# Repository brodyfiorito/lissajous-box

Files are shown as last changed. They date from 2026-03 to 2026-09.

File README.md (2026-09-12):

# Lissajous Figure Generator
A compact, standalone signal generator that produces phase- and frequency-controlled stereo sine waves for Lissajous figure visualization on an oscilloscope. Built around an ESP32-S3 and a PCM5102A stereo DAC, the device outputs two independent audio-frequency signals with real-time control over frequency ratio and phase offset via onboard potentiometers. It also functions as a USB-C audio speaker, with the ESP32-S3 acting as a USB audio device for music visualization on the oscilloscope.

## Overview
When two sine waves are fed into the X and Y inputs of an oscilloscope, the resulting trace is a Lissajous figure — a pattern whose shape is determined entirely by the frequency ratio and phase offset between the two signals. A 1:1 ratio at 90° produces a circle. A 2:1 ratio produces a figure eight. Higher integer ratios yield increasingly complex looping patterns.
Lissjous figure examples

It's a classic technique for visualizing the relationship between two signals, and the motivation behind this project. The device generates both signals digitally using an ESP32-S3 and outputs them through a PCM5102A stereo DAC, producing clean analog sine waves on two independent channels. Frequency ratio and phase offset are controlled via onboard potentiometers, making it a fully self-contained Lissajous generator.

### Key Features:
* Custom 2-layer PCB design in Altium Designer
* Dual-channel sine wave output via I²S audio DAC
* Real-time frequency ratio and phase offset control
* FreeRTOS-based firmware with state machine architecture
* USB-C audio input mode for music visualization.
* OLED display of frequency ratio and phase difference

## Hardware
### System Architecture
| Block | Component | Notes |
| --- | --- | --- |
| Microcontroller | ESP32-S3-WROOM-1-N4 |Dual-core, handles I²S output and control logic. Opens Bluetooth connectivity options |
| DAC | PCM5102A | 32-bit stereo audio DAC, I²S input |
| Power | TLV75733PDYDR | 1A LDO regulator; ESP32-S3 and PCM5102A draw well under 500mA combined |
| Input | 2x USB-C | One port used for programming the MCU, other used as a speaker |
| Output | 4x PCB Headers + JST male header | Left and right DAC output signals, plus two dedicated ground headers for oscilloscope probe referencing. OLED I²C port |

### Design Decisions

**LDO over buck converter:** The TLV75733PDYDR was chosen over a switching regulator specifically for noise performance. A buck converter operating at hundreds of kHz would inject switching noise onto the supply rail, which would appear directly on the PCM5102A analog output. An LDO produces a clean, low-noise 3.3V rail critical for signal integrity on an audio DAC.

**PCM5102A:** Selected for its stereo output and 32-bit resolution, providing more than enough dynamic range for clean sine wave generation. The internal charge pump also eliminates the need for an external negative supply rail, simplifying the power architecture.

**Output RC filter (1kΩ + 15nF):** The DAC output headers include a first-order low-pass filter with a cutoff frequency of ~10.6kHz. This was chosen to pass the full operating frequency range of 210–840Hz with minimal phase shift, while attenuating high-frequency noise and DAC imaging artifacts above the audio band. At 840Hz the phase shift introduced by this filter is under 5°, keeping both channels well-matched for accurate Lissajous figures.

**TVS diode on 5V input:** Protects the power rail from voltage transients on the USB input. USB ports can see inductive spikes during hot-plug events; the TVS clamps these before they reach the LDO or any downstream components.

**Color-coded test points:** Output headers use red (YRIGHT), white (XLEFT), and black (ground) test points to match standard oscilloscope probe color conventions, making it easy to connect the scope without referencing the schematic.

### Pin-Mapping
| Signal | GPIO | Notes |
| --- | --- | --- |
| OLED SDA | GPIO 1 | I²C data — OLED display |
| OLED SCL | GPIO 2 | I²C clock — OLED display |
| PHASE | GPIO 4 | Phase pot — ADC Channel 3 |
| FREQ | GPIO 5 | Frequency pot — ADC Channel 4 |
| MODE SWITCH | GPIO 6 | Mode selection switch |
| LRCK | GPIO 35 | I²S left/right clock |
| DOUT | GPIO 36 | I²S data out to DAC |
| BCK | GPIO 37 | I²S bit clock |
| SCK | GPIO 38 | I²S system clock (MCLK) |

### Schematics
All schematics were captured in Altium Designer.

Sheet 1

_Sheet 1 — Input/Output: Dual USB-C connectors (speaker and programming), CP2102-GMR USB-to-UART bridge for MCU programming, phase difference and frequency potentiometer inputs with R-C filtering, left and right DAC output headers with 1k series resistors and 15nF shunt capacitors, and USB D+/D− data lines with 22Ω series resistors._

Sheet 2

_Sheet 2 — Power: 5V to 3.3V regulation via TLV75733PDYDR LDO. Input is protected by a TVS diode with 1µF and 0.1µF decoupling capacitors. The EN pin is controlled by a 2.2kΩ/5kΩ resistor divider tied to the XSMT soft-mute signal. Output is decoupled with a 10µF capacitor, and a power indicator LED is driven through a 680Ω current-limiting resistor._

Sheet 3

_Sheet 3 — Audio: PCM5102A stereo DAC receiving I²S signals (SCK, BCK, DOUT, LRCK) from the ESP32-S3. AVDD, CPVDD, and DVDD are all supplied from 3.3V with 10µF and 0.1µF decoupling. Internal charge pump is supported by 2.2µF capacitors on CAPP and CAPM. Left (OUTL) and right (OUTR) analog outputs are routed to the output header section. XSMT soft-mute is tied to the power section EN divider._

Sheet 4

_Sheet 4 — MCU: ESP32-S3-WROOM-1-N4 with 10µF and 0.1µF decoupling on the 3.3V rail. I²S signals (LRCK, DOUT, BCK, SCK) are routed to the PCM5102A. UART RX/TX connect to the CP2102-GMR programming bridge via RTS/DTR auto-reset circuit — RTS and DTR signals drive NPN transistors through base resistors to control the EN and IO0 pins for automatic bootloader entry. USB D+/D− are broken out for USB audio (speaker) mode. Analog inputs receive the phase difference and frequency potentiometer signals. A mode selection switch with pull-down resistor and debounce capacitor is included. I²C lines (SCL, SDA) are broken out for the optional OLED display with decoupling on the supply line._

### Bill of Materials
| Ref | Description | Value / Part | Package | Qty |
|-----|---|---|---|-----|
| MCU | WiFi/BT Module | ESP32-S3-WROOM-1-N4 | SMD Module | 1 |
| DAC | Stereo DAC | PCM5102APWR | 20-TSSOP | 1 |
| PROG | USB-to-UART Bridge | CP2102-GMR | 28-QFN | 1 |
| U1 | LDO Regulator | TLV75733PDYDR | SOT-23-5 | 1 |
| J1, J2 | USB-C Connector | 2012670005 | SMD RA | 2 |
| P1 | OLED Header | Male Header 2mm 1×4 | 4-Pin THD | 1 |
| Q1, Q2 | NPN Transistor | SOT-1123 | SOT-1123 | 2 |
| R11 | Phase Potentiometer | ALPS RK11K1140A3L | 4-Pin THD | 1 |
| R12 | Frequency Potentiometer | ALPS RK11K1140A3L | 4-Pin THD | 1 |
| SW1 | Slide Switch | SPST 4A 125V | THD | 1 |
| R1–R4, R14 | Resistor | 5kΩ | 0603 | 5 |
| R5, R6, R9, R10 | Resistor | 1kΩ 1% 0.1W | 0603 | 4 |
| R7, R8 | Resistor | 22Ω 5% 0.1W | 0603 | 2 |
| R13 | Resistor | 2.2kΩ 1% 0.1W | 0603 | 1 |
| R15 | Resistor | 680Ω 5% | 0603 | 1 |
| R16, R17, R18 | Resistor | 10kΩ 0.1% | 0603 | 3 |
| C1, C7, C18 | Capacitor | 1µF | 0603 | 3 |
| C2, C3, C4, C9, C10, C11, C14, C16 | Capacitor | 0.1µF X7R | 0603 | 8 |
| C5, C6 | Capacitor | 15nF X7R | 0603 | 2 |
| C8, C15, C17 | Capacitor | 10µF X5R | 0603 | 3 |
| C12, C13 | Capacitor | 2.2µF X7S | 0603 | 2 |
| D1 | TVS Diode | 5V / 14V | 2×2 SON | 1 |
| D2 | LED | Red Clear | 2-SMD | 1 |
| SGND1, SGND2 | Test Point | Black Miniature | — | 2 |
| XLEFT | Test Point | White Miniature | — | 1 |
| YRIGHT | Test Point | Red Miniature | — | 1 |

### PCB Layout

PCB Top Layer

_Top copper layer showing primary signal and power routing. Stitching vias connect the top and bottom ground pours at regular intervals to minimize ground impedance and keep return current loops short._

PCB Bottom Layer

_Bottom copper layer. The continuous ground pour provides a low-impedance return path and acts as an electric field shield across the full board area._

PCB 3D View

_3D render of the assembled board. Controls (phase, frequency, mode) are grouped on the left edge; the DAC and analog outputs are isolated to the right edge away from the MCU and power circuitry._

#### Board Specifications
| Property | Value |
|---|---|
| Dimensions | 84 mm × 58 mm |
| Thickness | 1.6 mm |
| Finish | HASL |
| Layers | 2 |
| Top Layer | Primary signal and power routing |
| Bottom Layer | Ground plane |

#### Layer Stackup
Both layers carry continuous ground pours. The bottom ground plane serves as a low-impedance return path and voltage reference for analog signals, while the surrounding copper on both layers reduces capacitive coupling of external noise onto sensitive traces.

#### Placement
The CP2102 USB-UART bridge sits adjacent to the programming USB-C connector to keep the USB differential pair short. Decoupling capacitors are placed as close as possible to each IC's power pins to minimize supply rail loop inductance. The stereo DAC and analog output network are isolated to one edge of the board, maximizing separation from the ESP32 and power circuitry. The ESP32-S3 module antenna keepout area is free of copper pours and routing on all layers.

#### Routing
Ground vias are distributed across the board to connect the top and bottom ground pours, reducing ground impedance and keeping return current loops short.
Signal traces crossing power traces do so at 90° to minimize inter-layer capacitive coupling.
Analog output traces are routed away from digital and power traces for the full length of the board.

## Controls

The device has three physical controls: two potentiometers and a mode slide switch.

| Control | Function |
|---|---|
| Frequency pot | Selects frequency ratio between channels |
| Phase pot | Selects phase offset between channels |
| Mode switch | Toggles between Lissajous generator and USB audio input modes |

### Frequency Ratios
| Pot Position | Ratio | Pattern |
|---|---|---|
| 1 | 1:1 | Ellipse / circle |
| 2 | 2:1 | Figure eight |
| 3 | 3:1 | Three-lobed curve |
| 4 | 4:1 | Four-lobed curve |
| 5 | 1:2 | Horizontal figure eight |
| 6 | 3:2 | Three/two curve |
| 7 | 4:3 | Four/three curve |
| 8 | 6:5 | Six/five curve |

### Phase Steps
| Pot Position | Phase Offset |
|---|---|
| 1 | 0 |
| 2 | π/8 |
| 3 | π/4 |
| 4 | 3π/8 |
| 5 | π/2 |
| 6 | 5π/8 |
| 7 | 3π/4 |
| 8 | 7π/8 |

### Modes
**Lissajous Mode** — The ESP32-S3 generates both sine wave channels internally. Frequency ratio and phase offset are controlled via the onboard potentiometers. Connect XLEFT and YRIGHT outputs to the X and Y inputs of an oscilloscope in XY mode.

**Audio Input Mode** — The ESP32-S3 enumerates as a USB audio device. Audio played from a connected computer is passed through to the DAC outputs, allowing music to be visualized on the oscilloscope in XY mode.

## Firmware

The firmware is written in Embedded C using the ESP-IDF framework with FreeRTOS. Sine wave generation uses a phase accumulator, rather than computing sine values from absolute time, each sample increments a floating-point phase register by a step size proportional to the desired frequency, which avoids unbounded growth of the time variable. I²S is used to communicate with the DAC and I²C is used to communicate with the OLED controller.

### Architecture Highlights:
* FreeRTOS task handles I²S DMA buffer filling at audio sample rate
* State machine manages mode switching
* Phase accumulator for drift-free, long-term stability
* Exponential moving average + hysteresis on ADC pot readings to prevent jitter and snap between ratio/phase steps cleanly
* OLED display continuously updated via I²C with current frequency ratio and phase offset

Built with ESP-IDF v5.5.2

### Base Frequency Selection
The base frequency is 210Hz against a 44.1kHz sample rate, which is exactly 210 samples per cycle. Choosing a base frequency that divides evenly into the sample rate matters more than the specific value: any fractional remainder leaves a sub-sample timing error that accumulates cycle over cycle, and because the Lissajous figure is a picture of the phase relationship between the two channels, that error shows up directly as a figure that slowly precesses instead of standing still. See [Troubleshooting](#firmware-bring-up-and-troubleshooting) below.

## Development
### Devkit Prototype
Initial development and firmware validation were done on an ESP32-S3 devkit connected to a PCM5102A breakout board. During testing, the left channel output of the PCM5102A breakout was found to be non-functional. The right channel operated correctly. To rule out a firmware bug, the left and right channels were swapped in software, confirming the issue was a hardware fault on the breakout module rather than anything in the code. A bench signal generator was substituted as the left channel input to the oscilloscope, allowing firmware validation and Lissajous figure generation to continue. Outside of the broken channel, the devkit setup was used to fully validate the signal generation algorithm, I²S configuration, and oscilloscope output before committing to PCB layout.

ESP32 on a breadboard
_Breadboard prototype — ESP32-S3 devkit connected to PCM5102A breakout via jumper wires. Oscilloscope probe attached to OUTR and ground. Phase and frequency potentiometers wired in via jumper wires._

Two sine waves
_Rigol DS1102E oscilloscope showing early firmware output. CH1 (yellow) is the signal generator left channel reference, CH2 (blue) is OUTR from the PCM5102A; both set to 210Hz. The frequency readout is being thrown off by noise on the signals._

<video src="https://github.com/user-attachments/assets/7f4eb666-647e-48f4-968a-9c4041df8248" controls width="600"></video>
_Rigol DS1102E in XY mode. 210Hz on both channels with a phase offset producing a rotating ellipse pattern. CH1 (signal generator) on the X axis, CH2 (PCM5102A OUTR) on the Y axis._

### Firmware Bring-Up and Troubleshooting

Bring-up was done in order — supply rails, then I²S clocking, then the output waveforms — rather than by probing around. The Lissajous figure itself is a useful test signal: a 1:1 ratio at 90° should be a stationary circle, so anything wrong with channel amplitude matching, phase, or timing distorts the figure in a characteristic way. Every fault below was found on the devkit before the PCB was laid out.

#### No output — I²S clock configuration
The DAC produced nothing on either channel initially. The PCM5102A breakout ties SCK to ground internally, which puts the part in its internal-PLL mode and means it must not be fed an external master clock. Driving MCLK from the ESP32 anyway prevented the PLL from locking. The fix was to set MCLK to `I2S_GPIO_UNUSED` in the channel config, remove the manual `gpio_config()` calls that were being applied to the I²S pins (the I²S driver configures them itself), and bond the devkit and breakout grounds together rather than relying on separate supply returns.

#### Watchdog resets
Two separate causes. First, the `PI` constant was defined without an `f` suffix, which promoted the entire per-sample sine computation to double precision — the ESP32-S3 has no double-precision FPU, so the buffer fill loop no longer finished within its budget. Second, `ESP_LOGI` calls left inside the per-sample loop were writing to UART thousands of times per buffer. Adding the `f` suffix and pulling logging out of the inner loop resolved both.

#### Silent output before the first ADC read
`freqRatio` and `phaseDiff` were declared as `volatile float` globals with no initializer, so they were zero until `adc_task` completed its first read. With `freqRatio` at zero, the right channel step size was zero and its accumulator never advanced, producing a DC level instead of a sine. Initializing them to `1.0f` and `PI / 2.0f` means the I²S task generates a valid signal from the first buffer.

#### Precessing figure
With both channels at the same frequency and a fixed phase offset, the figure should be completely stationary. Instead it smeared into a blob. The base frequency at the time was 200Hz, which is 220.5 samples per cycle at 44.1kHz — the half-sample remainder accumulated as a slowly growing phase error between the channels, rotating the ellipse continuously. Moving the base frequency to 210Hz (exactly 210 samples per cycle) locked the figure in place.

#### Discontinuities at buffer boundaries
`freqRatio` and `phaseDiff` were being read inside the per-sample loop, so `adc_task` could change them partway through a buffer fill and split one buffer across two different parameter sets. Both are now snapshotted once at the top of each buffer fill and not re-read until the next one. Separately, the two accumulators were advancing independently, which allowed them to drift apart over long runtimes; the right channel phase is now derived from the left rather than accumulated on its own.

#### Periodic spikes on the sine output — phase accumulator
The most instructive fault. The output carried sharp spikes riding on an otherwise clean sine, frequent enough to destabilize the scope's frequency readout. Mains coupling was the obvious suspect: this was a breadboard with long jumper leads, and real 60Hz pickup had already turned up earlier in the project on a floating output.

The spectrum settled it. Coupled mains is an independent signal, so its energy lands at 60Hz and multiples of 60Hz, which are incommensurate with a 210Hz fundamental. The FFT instead showed a dip at 60Hz and energy at exact multiples of 210Hz. Harmonically related energy means the waveform's own shape is wrong — distortion generated inside the signal chain, periodic at the signal rate — rather than something unrelated being added to it from outside. A sharp, narrow glitch occurring once per output cycle spreads energy broadly across the harmonic series, which is exactly the signature observed.

That narrowed it to the generation path, and the time-domain trace confirmed it: the waveform was snapping back to θ = 0 rather than wrapping smoothly. The accumulator was being reset instead of reduced modulo 2π, so every wrap threw away the fractional phase advance and inserted a discontinuity. Wrapping by subtracting 2π when the accumulator passes it, and snapshotting parameters per buffer as described above, removed the spikes.

The general form is worth keeping on the bench: **harmonically related energy points at your own signal chain; unrelated frequencies point at the outside world.**

accumulator-error

_Phase accumulator resetting instead of wrapping. CH2 (blue) is OUTR from the PCM5102A — the trace climbs and then snaps back discontinuously once per cycle instead of turning over smoothly. CH1 (yellow) is the bench signal generator reference at 209.994Hz. Note that the FFT shown in the lower pane is sourced from CH1, not CH2 — this capture documents the time-domain reset, not the harmonic spectrum that ruled out mains coupling._

#### ADC filtering
The exponential moving average on the pot readings had its coefficients inverted — 5% previous value, 95% new sample — which is effectively no filtering, and the displayed ratio and phase jittered constantly. Corrected to 95% previous, 5% new, with a hysteresis window on top so the output only snaps to a new ratio or phase step once the pot has clearly moved into it.

#### Dead code
A zero-crossing block that reassigned `fL = base_freq` inside the buffer fill loop was removed. It was a leftover from an earlier attempt at dynamic frequency updates and did nothing, since `fL` never changes; the phase accumulator needs no zero-crossing alignment to stay stable.

### Validated Output

Captures taken after the firmware fixes above, on the Rigol DS1102E in XY mode. CH1 on the X axis at 950mV/div, CH2 on the Y axis at 100mV/div, 100.0kSa. Each figure is stationary rather than drifting, which is the real result — a stable figure means both channels agree on frequency and hold a constant phase relationship indefinitely.

1:1 ratio, 45 degree phase offset

_1:1 ratio at 45° phase offset — a tilted ellipse. At 0° this collapses to a diagonal line and at 90° it opens into a circle, so the tilt and openness of the ellipse read directly as the phase offset between channels._

1:2 ratio, 0 degree phase offset

_1:2 ratio at 0° phase offset — horizontal figure eight. The two lobes are symmetric and the crossing point sits centered, indicating matched amplitude between channels._

1:3 ratio, 0 degree phase offset

_1:3 ratio at 0° phase offset. At zero phase the figure is degenerate: the curve doubles back on itself and is retraced in both directions rather than enclosing separate lobes, so the trace appears as a single open path._

1:3 ratio, 15 degree phase offset

_1:3 ratio at 15°. Introducing phase separates the outbound and return paths, and the degenerate curve begins to open into distinct loops._

1:3 ratio, 30 degree phase offset

_1:3 ratio at 30°. The loops are fully separated. Sweeping phase at a fixed ratio walks the figure continuously between the degenerate and fully open forms._

### PCB Assembly

PCBs were fabricated by JLCPCB (2-layer, HASL, 1.6mm). Solder paste was applied manually using a stencil, SMD components were placed by hand and reflowed. Through-hole components (potentiometers, slide switch, OLED header, output headers) were hand soldered after reflow.

taped

_Solder paste applied prior to reflow. Board taped down to prevent shifting._

reflow

_Post-reflow. Through-hole components not yet installed._

firstrev

_Fully assembled and powered up. Power LED on, wires soldered to ESP32 for manual bootloader entry while programming, wires replaced with jumpers after firmware was validated._

The SOT-1123 NPN transistors used for the CP2102 auto-reset circuit were lost during reflow and could not be recovered. The package is too small to place reliably by hand. Manual bootloader entry (hold BOOT, cycle reset) is required for programming.

## Enclosure
The enclosure was designed in Fusion 360 to fit the PCB. It features cutouts for the two potentiometers, the mode slide switch, and the SSD1306 OLED display, as well as openings for the speaker output jack, USB-C port, and the dual oscilloscope output connectors. Intended for FDM printing in PLA.

STL and STEP files for the box and face plate are available in the `/enclosure` directory.

lissajous-box-view2
_Fusion 360 render of the enclosure._

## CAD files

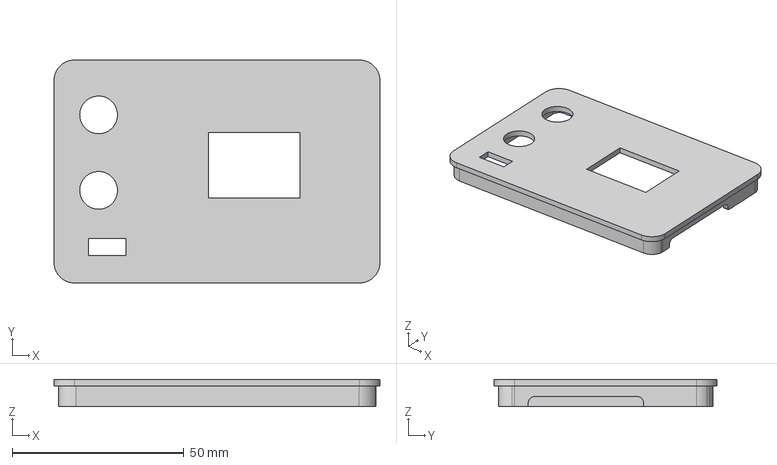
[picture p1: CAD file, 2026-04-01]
enclosure/Face Plate.step
95.0 x 65.0 x 8.00 mm

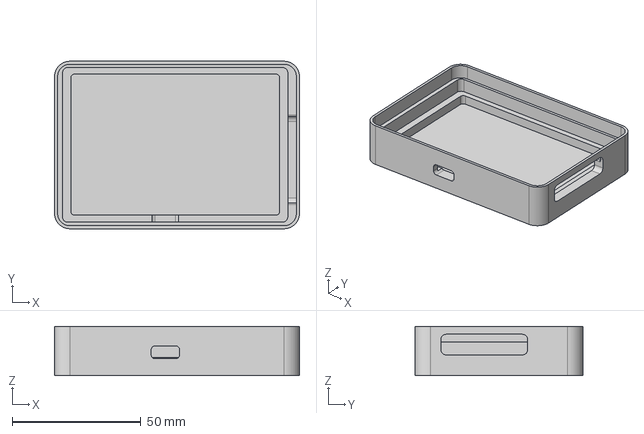
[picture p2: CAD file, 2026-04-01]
enclosure/Box.step
95.0 x 65.0 x 19.0 mm

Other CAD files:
enclosure/Box.stl
enclosure/Face Plate.stl

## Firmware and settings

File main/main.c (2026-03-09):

// Brody Fiorito 2026
// Lissajous Box - main.c
// Generates stereo sine waves with adjustable frequency ratio and phase offset
// for Lissajous figure display. 
// Also supports USB audio passthrough mode for music visualization.

#include <stdio.h>
#include <driver/uart.h>
#include <string.h>
#include <driver/gpio.h>
#include <driver/i2s_std.h>
#include <freertos/FreeRTOS.h>
#include <freertos/task.h>
#include <esp_adc/adc_cali.h>
#include <esp_adc/adc_cali_scheme.h>
#include <esp_adc/adc_oneshot.h>
#include <math.h>
#include <usb_device_uac.h>
#include <freertos/ringbuf.h>
#include "esp_log.h"

// Hardware Pins
#define LRCK_PIN GPIO_NUM_35
#define DOUT_PIN GPIO_NUM_36
#define BCK_PIN GPIO_NUM_37
#define SCK_PIN GPIO_NUM_38

#define PHASE_PIN GPIO_NUM_4
#define FREQ_PIN GPIO_NUM_5
#define PHASE_ADC_CHANNEL ADC_CHANNEL_3
#define FREQ_ADC_CHANNEL ADC_CHANNEL_4
#define MODE_SWITCH_PIN GPIO_NUM_9

// Constants
#define PI 3.14159265358979f
#define UAC_RX_BUFSIZE 4096
#define ADC_MV_MAX 3200.0f

// Global State
static RingbufHandle_t audio_ringbuf = NULL;

static i2s_chan_handle_t tx_chan;

volatile float freq_ratio = 1.0f;       // Shared between i2s_task and adc_task. Volatile prevents the compiler
volatile float phase_diff = PI / 2.0f;  // from optimizing reads into a register, ensuring the latest value is always used.

typedef struct {
    int last_raw;
    float smooth;
} adc_ctrl_t;

adc_ctrl_t freq_ctrl = { .last_raw = 0, .smooth = 0 };
adc_ctrl_t phase_ctrl = { .last_raw = 0, .smooth = 0 };

typedef enum {
    MODE_LISSAJOUS = 0,
    MODE_AUDIO_INPUT = 1
} system_state_t;

TaskHandle_t adc_sampling_handle = NULL;
TaskHandle_t audio_input_handle = NULL;
TaskHandle_t i2s_handle = NULL;

static system_state_t current_mode = MODE_LISSAJOUS;
static system_state_t requested_mode = MODE_LISSAJOUS;

// Function prototypes
void adc_task(void *arg);
void i2s_task(void *arg);
void audio_input_task(void *arg);
int adc_hysteresis(adc_ctrl_t *c, int);
float adc_smooth(adc_ctrl_t *c, int);
float get_ratio(float);
float get_phase_diff(float);
static esp_err_t uac_output_callback(uint8_t *buf, size_t len, void *cb_ctx);
void enter_mode(system_state_t);
static system_state_t read_mode_switch(void);

void i2s_task (void *arg) {

    // I2S Configuration
    i2s_chan_config_t chan_config = I2S_CHANNEL_DEFAULT_CONFIG(
        I2S_NUM_0,
        I2S_ROLE_MASTER
    );

    i2s_std_config_t i2s_config = {
        .clk_cfg = I2S_STD_CLK_DEFAULT_CONFIG(44100),

        .slot_cfg = I2S_STD_PHILIPS_SLOT_DEFAULT_CONFIG(
            I2S_DATA_BIT_WIDTH_16BIT,
            I2S_SLOT_MODE_STEREO
        ),

        .gpio_cfg = {
            .mclk = I2S_GPIO_UNUSED,
            .bclk = BCK_PIN,
            .ws = LRCK_PIN,
            .dout = DOUT_PIN,
            .din = I2S_GPIO_UNUSED,
            .invert_flags = {
                .mclk_inv = false,
                .bclk_inv = false,
                .ws_inv = false,
            },
        },
    };

    i2s_new_channel(&chan_config, &tx_chan, NULL);
    i2s_channel_init_std_mode(tx_chan, &i2s_config);
    i2s_channel_enable(tx_chan);

    const float base_freq = 210.0f;
    float phaseL = 0.0f;
    const float sample_rate = 44100.0f;
    const int BUFFER_SIZE = 256;
    int16_t buffer[BUFFER_SIZE * 2];

    while (1) {

        if (current_mode == MODE_LISSAJOUS) {

            float fL = base_freq;

            for (int i = 0; i < BUFFER_SIZE; i++) {
                float sampleL = sinf(phaseL);
                float sampleR = sinf(phaseL * freq_ratio + phase_diff);

                buffer[i*2 + 0] = (int16_t)(sampleL * 0x7FFF);
                buffer[i*2 + 1] = (int16_t)(sampleR * 0x7FFF);

                phaseL += 2.0f * PI * fL / sample_rate;

                if (phaseL >= 2.0f * PI) phaseL -= 2.0f * PI;
            }

            size_t bytes_written;
            i2s_channel_write(tx_chan, buffer, sizeof(buffer), &bytes_written, portMAX_DELAY);

        } else if (current_mode == MODE_AUDIO_INPUT) {

            if (audio_ringbuf == NULL) {
                vTaskDelay(pdMS_TO_TICKS(10));
                continue;
            }

            size_t bytes_available;
            uint8_t *data = (uint8_t *)xRingbufferReceiveUpTo(
                audio_ringbuf,
                &bytes_available,
                pdMS_TO_TICKS(20),  // Block up to 20ms waiting for data; sizeof(buffer) caps the read to our
                sizeof(buffer)      // output buffer size. If no data arrives we loop and retry rather than stall.
            );

            if (data && bytes_available > 0) {
                size_t bytes_written;
                i2s_channel_write(tx_chan, data, bytes_available, &bytes_written, portMAX_DELAY);
                vRingbufferReturnItem(audio_ringbuf, data);
            }

        } else {
            // Should never reach here - unknown mode, yield to prevent CPU starvation
            vTaskDelay(1);
        }
    }
}

void adc_task(void *arg) {

    // Initialize ADC1 in oneshot mode for reading frequency and phase control potentiometers.
    // Oneshot mode is used instead of continuous mode since we only need periodic readings
    // at 10ms intervals, not a high-speed stream.
    adc_oneshot_unit_handle_t adc_handle;

    adc_oneshot_unit_init_cfg_t init_config = {
        .unit_id = ADC_UNIT_1
    };

    adc_oneshot_new_unit(&init_config, &adc_handle);

    adc_oneshot_chan_cfg_t chan_cfg = {
        .atten = ADC_ATTEN_DB_12,
        .bitwidth = ADC_BITWIDTH_12,
    };

    adc_oneshot_config_channel(adc_handle, FREQ_ADC_CHANNEL, &chan_cfg);

    adc_oneshot_config_channel(adc_handle, PHASE_ADC_CHANNEL, &chan_cfg);

    adc_cali_handle_t cali_handle;

    adc_cali_curve_fitting_config_t cali_cfg = {
        .unit_id = ADC_UNIT_1,
        .atten = ADC_ATTEN_DB_12,
        .bitwidth = ADC_BITWIDTH_12,
    };

    adc_cali_create_scheme_curve_fitting(&cali_cfg, &cali_handle);

    while (1) {

        int raw_freq, mv_freq;
        int raw_phase, mv_phase;

        adc_oneshot_read(adc_handle, FREQ_ADC_CHANNEL, &raw_freq);
        adc_oneshot_read(adc_handle, PHASE_ADC_CHANNEL, &raw_phase);

        adc_cali_raw_to_voltage(cali_handle, raw_freq, &mv_freq);   // Calibrates raw ADC values to mV
        adc_cali_raw_to_voltage(cali_handle, raw_phase, &mv_phase);

        mv_freq = adc_hysteresis(&freq_ctrl, mv_freq);
        mv_phase = adc_hysteresis(&phase_ctrl, mv_phase);

        float freq_norm = adc_smooth(&freq_ctrl, mv_freq) / ADC_MV_MAX;     // Normalizes from 0-1
        float phase_norm = adc_smooth(&phase_ctrl, mv_phase) / ADC_MV_MAX;

        freq_ratio = get_ratio(freq_norm);
        phase_diff = get_phase_diff(phase_norm);

        vTaskDelay(pdMS_TO_TICKS(10));
    }
}

void audio_input_task(void *arg) {

    // Make ring buffer, computer puts data in back while DAC picks up data from front
    audio_ringbuf = xRingbufferCreate(UAC_RX_BUFSIZE, RINGBUF_TYPE_BYTEBUF);

    // Configure and start UAC
    uac_device_config_t uac_cfg = {
        .output_cb = uac_output_callback,
        .input_cb = NULL,
        .set_mute_cb = NULL,
        .set_volume_cb = NULL,
        .cb_ctx = NULL,
    };

    uac_device_init(&uac_cfg);

    // Task stays alive to keep UAC initialized; audio data is handled via uac_output_callback
    while (1) {
        vTaskDelay(portMAX_DELAY);
    }
}

void app_main(void)
{

    // Configuring GPIO
    gpio_set_direction(PHASE_PIN, GPIO_MODE_INPUT);
    gpio_set_direction(FREQ_PIN, GPIO_MODE_INPUT);

    gpio_config_t io_conf = {
        .pin_bit_mask = (1ULL << MODE_SWITCH_PIN),
        .mode = GPIO_MODE_INPUT,
        .pull_up_en = GPIO_PULLUP_DISABLE,
        .pull_down_en = GPIO_PULLDOWN_DISABLE,
        .intr_type = GPIO_INTR_DISABLE
    };
    gpio_config(&io_conf);

    // Start persistent i2s task and enter into default mode
    xTaskCreate(
            i2s_task,
            "I2S_task",
            8192,
            NULL,
            5,
            &i2s_handle
        ); 

    enter_mode(MODE_LISSAJOUS);

    while (1) {

        requested_mode = read_mode_switch();

        if (requested_mode != current_mode) {
            enter_mode(requested_mode);
        }

        vTaskDelay(pdMS_TO_TICKS(100));
    }
}

////////////////// Helper Functions //////////////////

#define ADC_HYST 10     // Amount of millivolts in order to cause change in output value

int adc_hysteresis(adc_ctrl_t *c, int raw)
{
    int delta = raw - c->last_raw;

    if (delta > ADC_HYST) {
        c->last_raw += ADC_HYST;
    } else if (delta < -ADC_HYST) {
        c->last_raw -= ADC_HYST;
    }

    return c->last_raw;
}

float adc_smooth(adc_ctrl_t *c, int val) {

    c->smooth = 0.95f * c->smooth + 0.05f * val; // 95% old, 5% new creates an exponential moving average
    return c->smooth;
}

// Translate millivolts to ratio between frequencies
float get_ratio(float freq_norm) {

    if (freq_norm < 1.0f/8.0f) return 1.0f;         // 1:1 ratio
    if (freq_norm < 2.0f/8.0f) return 2.0f;         // 2:1 ratio
    if (freq_norm < 3.0f/8.0f) return 3.0f;         // 3:1 ratio
    if (freq_norm < 4.0f/8.0f) return 4.0f;         // 4:1 ratio
    if (freq_norm < 5.0f/8.0f) return 0.5f;         // 1:2 ratio
    if (freq_norm < 6.0f/8.0f) return 1.5f;         // 3:2 ratio
    if (freq_norm < 7.0f/8.0f) return 4.0f/3.0f;    // 4:3 ratio
    return 6.0f/5.0f;                               // 6:5 ratio
}

// Translate millivolts to phase difference
float get_phase_diff(float phase_norm) {

    if (phase_norm < 1.0f/8.0f) return 0;
    if (phase_norm < 2.0f/8.0f) return PI/8.0f;
    if (phase_norm < 3.0f/8.0f) return PI/4.0f;
    if (phase_norm < 4.0f/8.0f) return PI*3.0f/8.0f;
    if (phase_norm < 5.0f/8.0f) return PI/2.0f;
    if (phase_norm < 6.0f/8.0f) return PI*5.0f/8.0f;
    if (phase_norm < 7.0f/8.0f) return PI*3.0f/4.0f;
    return PI*7.0f/8.0f;
}

static esp_err_t uac_output_callback(uint8_t *buf, size_t len, void *arg) {

    if (audio_ringbuf) {
        xRingbufferSend(audio_ringbuf, buf, len, 0);    // Timeout of 0 drops data if the buffer is full
    }

    return ESP_OK;
}

////////////////// State Machine Functions //////////////////

void enter_mode(system_state_t mode) {

    // Cleans up tasks that are no longer in use, lowers task load before transitioning to new mode
    if (adc_sampling_handle) {
        vTaskDelete(adc_sampling_handle);
        adc_sampling_handle = NULL;
    }

    if (audio_input_handle) {
        vTaskDelete(audio_input_handle);
        audio_input_handle = NULL;
    }

    if (audio_ringbuf) {
        vRingbufferDelete(audio_ringbuf);
        audio_ringbuf = NULL;
    }

    switch (mode) {

        case MODE_LISSAJOUS:

            xTaskCreate(
            adc_task,
            "ADC_Sampling",
            4096,
            NULL,
            3,
            &adc_sampling_handle
            ); 

            break;

        case MODE_AUDIO_INPUT:

            xTaskCreate(
            audio_input_task,
            "Audio_Input",
            8192,
            NULL,
            5,
            &audio_input_handle
            );

            break;
    }
    current_mode = mode;
}

// Reads mode switch on board to determine requested mode
static system_state_t read_mode_switch(void) {
    return gpio_get_level(MODE_SWITCH_PIN) ? MODE_AUDIO_INPUT : MODE_LISSAJOUS;
}

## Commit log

2026-03-02 Refactor, resolved PCM5102A PLL lock, phase drift, and WDT issues in I2S signal generation
    [main.c]
2026-03-09 Initial README
    Add full project README covering hardware architecture, schematics, BOM, firmware design, devkit development history, and controls reference
2026-04-01 docs: add enclosure section and update roadmap
2026-04-01 add enclosure files
    [Box.step, Box.stl, Face Plate.step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]
2026-05-01 docs: add pictures of first pcb revision
2026-05-12 docs: pcb assembly details
